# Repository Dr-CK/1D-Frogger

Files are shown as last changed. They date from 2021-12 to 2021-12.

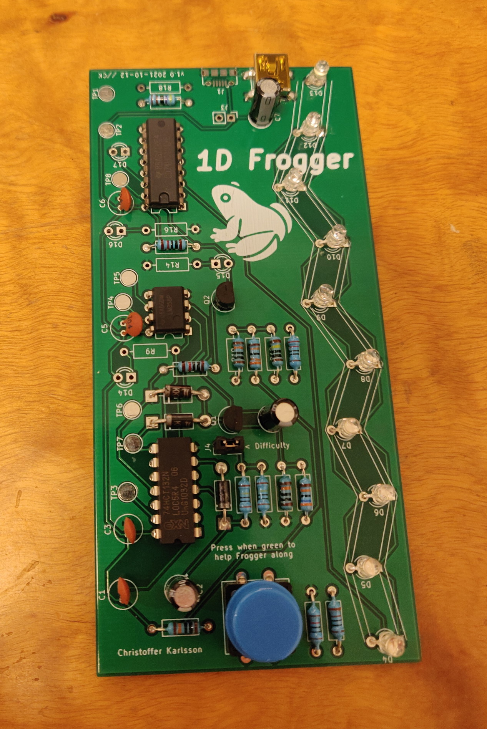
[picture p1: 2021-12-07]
Circuit board.jpg

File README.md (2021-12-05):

# 1D-Frogger
KiCAD project files for a minimalist one dimensional game of Frogger

See BOM for components and assembly notes

How to play the game:
* Press the button while the light is green to advance Frogger until you reach the final light.
* If you press it while it's red, Frogger goes back to the starting position.
* The flashing will be faster and faster, so act quickly!
* The difficulty can be adjusted by shorting the J4 pins with a jumper (faster flashing).

CC BY-NC-SA

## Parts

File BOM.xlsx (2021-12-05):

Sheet: Details
Frogger 1D BOM
Code | Component value | Comment
ICs
U1 | 74HC4017 | Decade counter
U2 | LM358 | Operational amplifier
U3 | 74HCT132 | Schmitt trigger quad NAND gate
Resistors
R1 | 100k
R2 | 10k
R3 | 1k | For red LEDs
R4 | 1M
R5 | 1M
R6 | 100k
R7 | 360k
R8 | 10k
R9 | N/A | *Optional (~220 ohm), for testing
R10 | 100k
R11 | 300k
R12 | 1M
R13 | 220 ohm | For green LEDs
R14 | N/A | *; Has to be >1k if used
R15 | 10k
R16 | N/A | *
R17 | 4.7k-10k | For white LED
R18 | N/A | *
Capacitors
C1 | 0.1µF ceramic
C2 | 2.2 µF electrolytic | *White = cathode; +,square = anode
C3 | 0.1µF ceramic
C4 | 10 µF electrolytic | *
C5 | 0.1µF ceramic
C6 | 0.1µF ceramic
C7 | 10 µF electrolytic | *
Diodes
D1 | 1N4001 | *Line, square = cathode
D2 | 1N4001 | *
D3 | 1N4001 | *
D4-D12 | Red/green common anode LEDs | Center = anode (longest leg); square = green (shortest leg)
D13 | White LED | **Square = cathode
D14-D17 | N/A | Optional LEDs for testing; **
Transistors |  | N.B. Pads are very close together, solder with care!
Q1 | BC557 | PNP
Q2 | PN2222 | NPN
Connectors
J1 | USB-B micro | *One power supply (J1, J2 or J3)
J2 | USB-B mini | *
J3 | Pin header power supply | Square = +5V; circle = GND; *
J4 | Pin header with jumper | Short-circuit pins for higher difficulty
Switches
SW1 | Momentary push button | *One switch (SW1 or SW2)
SW2 | Momentary push button | *
Test points
TP1 | N/A | Ground
TP2 | N/A | +5V
TP3 | N/A | PUSH
TP4 | N/A | GO
TP5 | N/A | /GO
TP6 | N/A | /RST
TP7 | N/A | /HLT
TP8 | N/A | RST

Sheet: BOM
Frogger 1D BOM
Component | Number | Price Dec 2021 | Total cost
74HC4017 | 1 | 5.90 | 5.90
LM358 | 1 | 3.75 | 3.75
74HCT132 | 1 | 7.50 | 7.50
220 ohm | 1 | 0.60 | 0.60
1k | 1 | 0.60 | 0.60
4.7k | 1 | 0.60 | 0.60
10k | 3 | 0.60 | 1.80
100k | 3 | 0.60 | 1.80
300k | 1 | 1.50 | 1.50
360k | 1 | 1.50 | 1.50
1M | 3 | 0.60 | 1.80
0.1µF ceramic cap | 4 | 1.50 | 6.00
2.2 µF electrolytic cap | 1 | 0.94 | 0.94
10 µF electrolytic cap | 2 | 0.62 | 1.24
1N4001 diodes | 3 | 0.75 | 2.25
Red/green common anode LEDs | 9 | 2.25 | 20.25
White LED | 1 | 4.50 | 4.50
BC557 | 1 | 0.94 | 0.94
PN2222 | 1 | 1.50 | 1.50
USB connector | 1 | 7.42 | 7.42
Pin header | 1 | 0.40 | 0.40
Jumper | 1 | 1.00 | 1.00
Momentary push button | 1 | 5.00 | 5.00
Sum |  |  | 78.79

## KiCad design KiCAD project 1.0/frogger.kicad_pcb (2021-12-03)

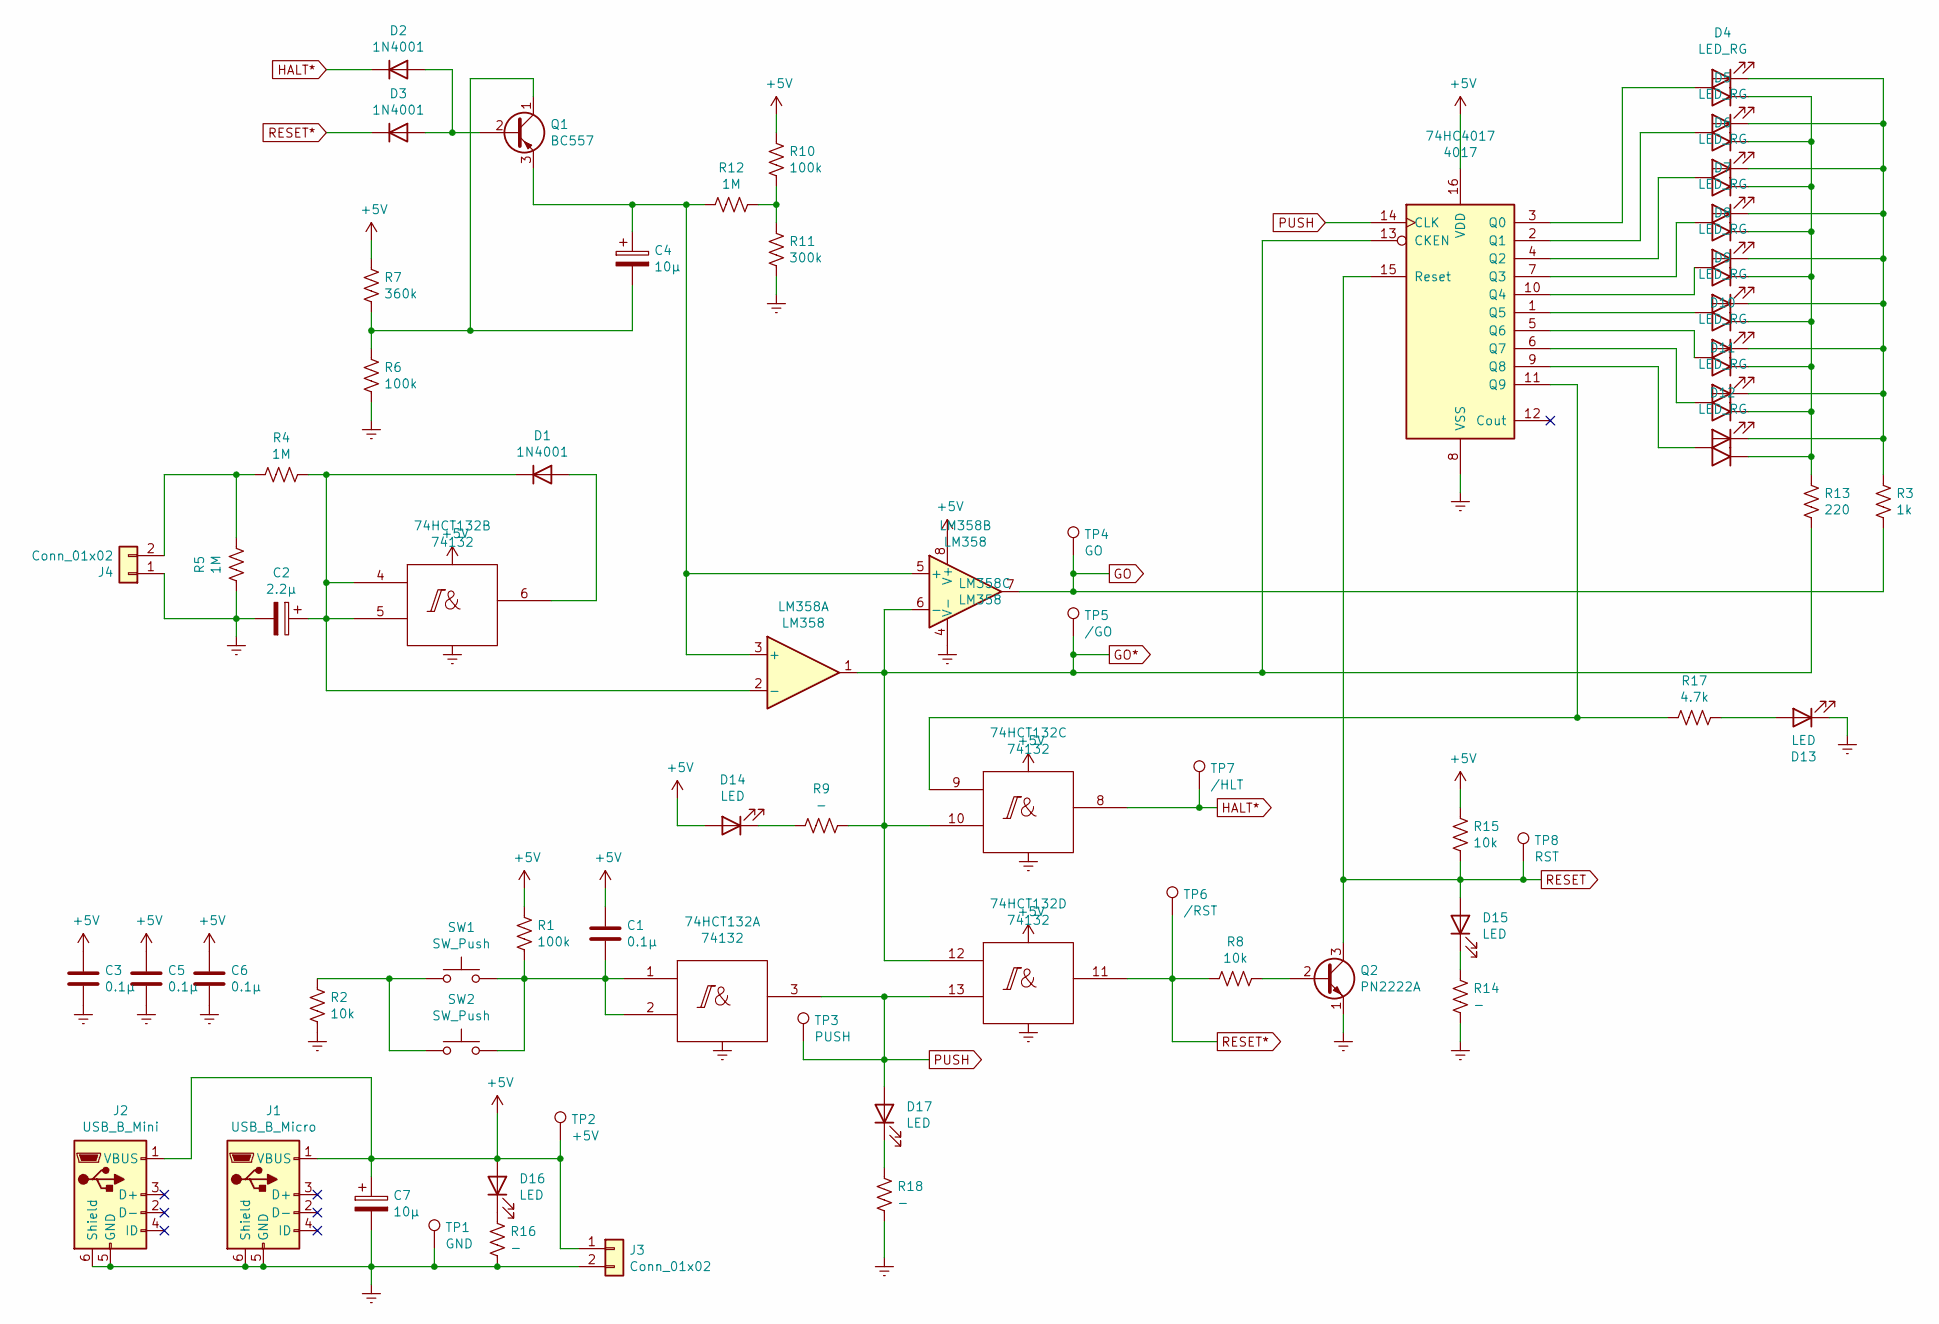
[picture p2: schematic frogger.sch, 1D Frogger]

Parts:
74HC4017: 4017; DIP-16_W7.62mm
74HCT132: 74132; DIP-14_W7.62mm
C1, C3, C5, C6: 0.1µ; C_Radial_D5.0mm_H7.0mm_P2.00mm
C2: 2.2µ; CP_Radial_D5.0mm_P2.50mm
C4, C7: 10µ; CP_Radial_D5.0mm_P2.50mm
D1, D2, D3: 1N4001; D_DO-41_SOD81_P10.16mm_Horizontal
D4, D5, D6, D7, D8, D9, D10, D11, D12: LED_RG; LED_D3.0mm-3
D13, D14, D15, D16, D17: LED; LED_D3.0mm
J1: USB_B_Micro; USB_Micro-B_Amphenol_10118194_Horizontal
J2: USB_B_Mini; USB_Mini-B_Lumberg_2486_01_Horizontal
J3, J4: Conn_01x02; PinHeader_1x02_P2.54mm_Vertical
LM358: LM358; DIP-8_W7.62mm
Q1: BC557; TO-92_Inline
Q2: PN2222A; TO-92_Inline
R1, R6, R10: 100k; R_Axial_DIN0207_L6.3mm_D2.5mm_P10.16mm_Horizontal
R2, R8, R15: 10k; R_Axial_DIN0207_L6.3mm_D2.5mm_P10.16mm_Horizontal
R3: 1k
R4, R5, R12: 1M; R_Axial_DIN0207_L6.3mm_D2.5mm_P10.16mm_Horizontal
R7: 360k; R_Axial_DIN0207_L6.3mm_D2.5mm_P10.16mm_Horizontal
R9, R14, R16, R18: -; R_Axial_DIN0207_L6.3mm_D2.5mm_P10.16mm_Horizontal
R11: 300k; R_Axial_DIN0207_L6.3mm_D2.5mm_P10.16mm_Horizontal
R13: 220; R_Axial_DIN0207_L6.3mm_D2.5mm_P10.16mm_Horizontal
R17: 4.7k; R_Axial_DIN0207_L6.3mm_D2.5mm_P10.16mm_Horizontal
SW1: SW_Push; SW_PUSH-12mm
SW2: SW_Push; SW_PUSH_6mm
TP1: GND; TestPoint_Pad_D3.0mm
TP2: +5V; TestPoint_Pad_D3.0mm
TP3: PUSH; TestPoint_Pad_D3.0mm
TP4: GO; TestPoint_Pad_D3.0mm
TP5: /GO; TestPoint_Pad_D3.0mm
TP6: /RST; TestPoint_Pad_D3.0mm
TP7: /HLT; TestPoint_Pad_D3.0mm
TP8: RST; TestPoint_Pad_D3.0mm

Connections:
+5V: 74HC4017.16 (VDD), 74HCT132.14 (Vcc), C1.1, C3.1, C5.1, C6.1, C7.1, D14.2 (A), D16.2 (A), J1.1 (VBUS), J2.1 (VBUS), J3.1, LM358.8 (V+), R1.1, R7.1, R10.1, R15.1, TP2.1
Earth: 74HC4017.8 (VSS), 74HCT132.7 (Gnd), C2.2, C3.2, C5.2, C6.2, C7.2, D13.1 (K), J1.5 (GND), J1.6 (Shield), J2.5 (GND), J2.6 (Shield), J3.2, J4.1, LM358.4 (V-), Q2.1 (E), R2.2, R5.2, R6.2, R11.2, R14.2, R16.2, R18.2, TP1.1
GO: LM358.7, R3.2, TP4.1
GO*: 74HC4017.13 (CKEN), 74HCT132.10, 74HCT132.12, LM358.1, LM358.6 (-), R9.1, R13.2, TP5.1
HALT*: 74HCT132.8, D2.1 (K), TP7.1
unnamed: 74HC4017.1 (Q5), D9.2 (A)
unnamed: 74HC4017.2 (Q1), D5.2 (A)
unnamed: 74HC4017.3 (Q0), D4.2 (A)
unnamed: 74HC4017.4 (Q2), D6.2 (A)
unnamed: 74HC4017.5 (Q6), D10.2 (A)
unnamed: 74HC4017.6 (Q7), D11.2 (A)
unnamed: 74HC4017.7 (Q3), D7.2 (A)
unnamed: 74HC4017.9 (Q8), D12.2 (A)
unnamed: 74HC4017.10 (Q4), D8.2 (A)
unnamed: 74HC4017.11 (Q9), 74HCT132.9, R17.2
unnamed: 74HCT132.1, 74HCT132.2, C1.2, R1.2, SW1.2, SW2.2
unnamed: 74HCT132.4, 74HCT132.5, C2.1, D1.1 (K), LM358.2 (-), R4.1
unnamed: 74HCT132.6, D1.2 (A)
unnamed: C4.1, LM358.3 (+), LM358.5 (+), Q1.3 (E), R12.2
unnamed: C4.2, Q1.1 (C), R6.1, R7.2
unnamed: D2.2 (A), D3.2 (A), Q1.2 (B)
unnamed: D4.1 (G), D5.1 (G), D6.1 (G), D7.1 (G), D8.1 (G), D9.1 (G), D10.1 (G), D11.1 (G), D12.1 (G), R13.1
unnamed: D4.3 (R), D5.3 (R), D6.3 (R), D7.3 (R), D8.3 (R), D9.3 (R), D10.3 (R), D11.3 (R), D12.3 (R), R3.1
unnamed: D13.2 (A), R17.1
unnamed: D14.1 (K), R9.2
unnamed: D15.1 (K), R14.1
unnamed: D16.1 (K), R16.1
unnamed: D17.1 (K), R18.1
unnamed: J4.2, R4.2, R5.1
unnamed: Q2.2 (B), R8.1
unnamed: R2.1, SW1.1, SW2.1
unnamed: R10.2, R11.1, R12.1
PUSH: 74HC4017.14 (CLK), 74HCT132.3, 74HCT132.13, D17.2 (A), TP3.1
RESET: 74HC4017.15 (Reset), D15.2 (A), Q2.3 (C), R15.2, TP8.1
RESET*: 74HCT132.11, D3.1 (K), R8.2, TP6.1

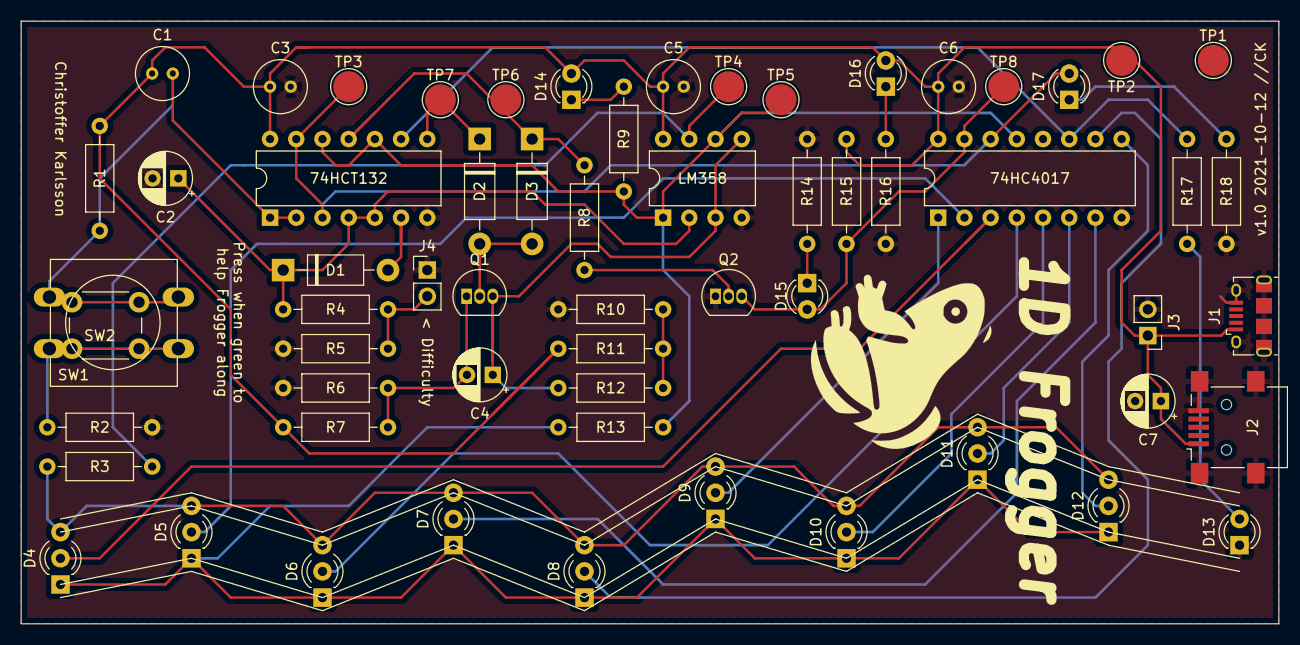
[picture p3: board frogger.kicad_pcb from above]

Board: 2 copper layers, 121.9 x 58.4 mm, 62 parts (0 on the bottom side), 35 nets.

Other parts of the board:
ICON: FROG; frog1

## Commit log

2021-12-03 KiCAD project
    [frogger-B_Cu.gbl, frogger-B_Mask.gbs, frogger-B_Paste.gbp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]
2021-12-05 KiCAD project 1.0
    [BOM.xlsx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]
2021-12-05 Update BOM
    [BOM.xlsx]
2021-12-07 Picture of assembled circuit board
